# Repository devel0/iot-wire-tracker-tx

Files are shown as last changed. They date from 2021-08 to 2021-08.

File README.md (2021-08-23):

# iot-wire-tracker-tx

<!-- TOC -->
* [Description](#description)
* [Usage](#usage)
* [Notes](#notes)
* [Prototype example](#prototype-example)
* [How this project was built](#how-this-project-was-built)
<!-- TOCEND -->

<hr/>

## Description

Crude replacement for a damaged wire tracker tx module.

Generates a square signal train ( 50% duty ) on pin 9 suitable for a wire tracker receiver with follow train sequence:
- 50ms @2500 hz
- 50ms @833 hz
- 50ms @625 hz

Signal will completely disabled if red/black wire shorts due to triggering on pin 2 ; it will restart when short removed.

[schematic](https://oshwlab.com/lorenzo.delana/iot-wire-tracker-tx)

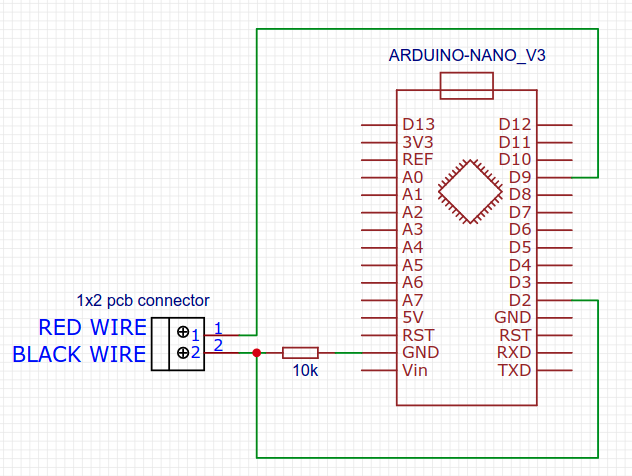
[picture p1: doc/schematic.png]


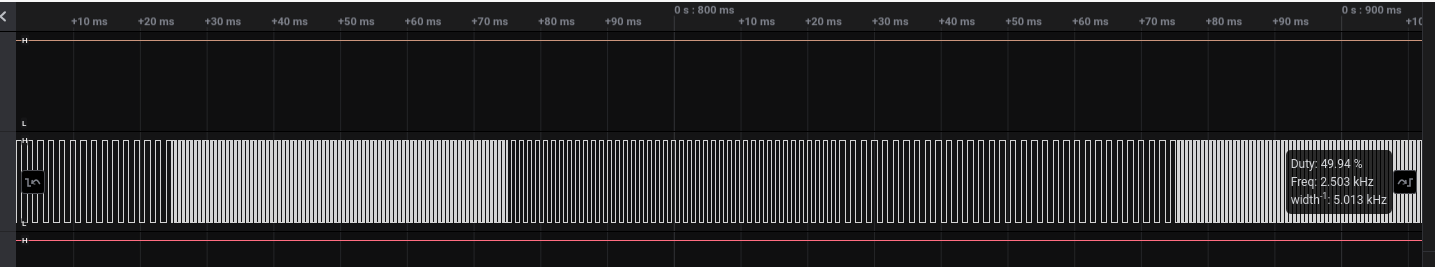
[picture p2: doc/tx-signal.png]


## Usage

example:
| **tx side** | **other side** |
|---|---|
| cable_txred | cable_unk1 |
| cable_black | cable_unk2 |
|  | ... |
|  | cable_unkX |

:warning: **Warnings** :
- ensure no voltage present on cables either for the tx side and other side cables

- connect cable_txred to the pin 9
- connect cable_black to the 10k resistor that in turn connects to GND 
- go to the other side with the wire tracker rx tool ( not provided ) that amplify into a speaker detected signal moving the point on wires
- two wires ( corresponding to the counterpart cable_txred and cable_black ) produces high volume on speaker
- counterverify if cable_unk1 e and cable_unk2 are those searched by connecting them together and if the speaker stop this mean that they are those matching source tx. during this phase the arduino led will blink fast.
- place a mark on two wires matched
- **important** : go to the tx side and disconnect cable_txred, cable_black before to reapply any voltage on cables or tx module could get damaged

## Notes
- 10k resistor allow to safely short circuit between red, black wire to cancel the signal in the counterverify step without destroy the pin9 port because of high level output while connects to gnd ( black cable )

## Prototype example

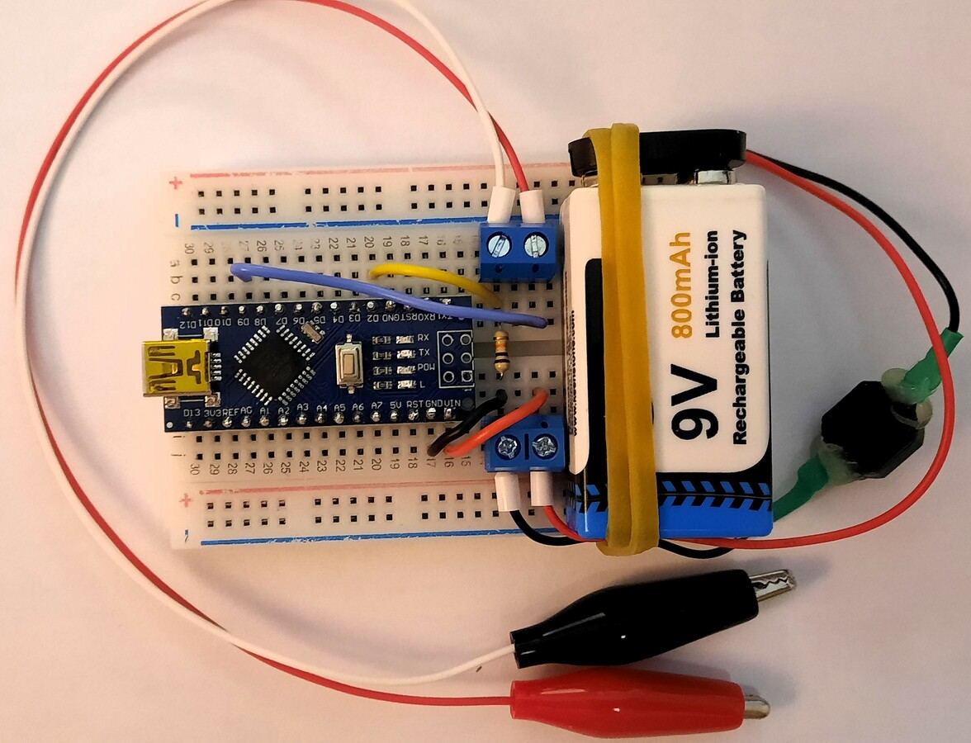
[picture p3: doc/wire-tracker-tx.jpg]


## How this project was built

- from platformio / projects / new selecting arduino nano (new bootloader)
- from platformio / libraries / added TimerInterrupt

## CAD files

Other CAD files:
arduino-nano.dwg

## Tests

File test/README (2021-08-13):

This directory is intended for PlatformIO Unit Testing and project tests.

Unit Testing is a software testing method by which individual units of
source code, sets of one or more MCU program modules together with associated
control data, usage procedures, and operating procedures, are tested to
determine whether they are fit for use. Unit testing finds problems early
in the development cycle.

More information about PlatformIO Unit Testing:
- https://docs.platformio.org/page/plus/unit-testing.html

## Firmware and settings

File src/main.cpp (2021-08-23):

// generates a square signal train ( 50% duty ) on pin 9
// suitable for a wire tracker transmitter
// RED WIRE -> pin 9
// BLACK WIRE -> 10k resistor -> gnd
//
// signal pattern sequence:
// - 50ms @2500 hz
// - 50ms @833 hz
// - 50ms @625 hz

// #define DEBUG // TODO: comment this on release

#include <Arduino.h>

#define OUT_PIN 9
#define IN_PIN 2
#define USE_TIMER_1 true

#include <TimerInterrupt.h>

#define TIMER_FREQ 10000

// 1/TIMER_FREQ * 2 * CNT_PHASE = 50ms phase switch time
int CNT_PHASE = 250;

bool val = false;
int val_cnt = 0;

int phase = 0;
int phase_cnt = 0;

volatile bool disabled = false;
volatile uint32_t m_in = millis();

void TimerISR()
{
  if (disabled)// && millis() - m_in > 500)
  {
    digitalWrite(OUT_PIN, HIGH);
    auto v = digitalRead(IN_PIN);
    if (v == LOW)
    {
      #ifdef DEBUG
      Serial.print(millis());
      Serial.println(" RE-ENABLE");
      #endif
      digitalWrite(LED_BUILTIN, LOW);
      disabled = false;
    }
    else
    {    
      return;
    }
  }

  if (phase_cnt > CNT_PHASE)
  {
    ++phase;
    if (phase > 2)
      phase = 0;
    phase_cnt = 0;
  }

  switch (phase)
  {

    // TIMER_FREQ / 4 = 2500hz
  case 0:
  {
    val = !val;
    digitalWrite(OUT_PIN, val ? HIGH : LOW);
  }
  break;

    // TIMER_FREQ / (4*3) = 833hz
  case 1:
  {
    if (val_cnt > 2)
    {
      val = !val;
      digitalWrite(OUT_PIN, val ? HIGH : LOW);
      val_cnt = 0;
    }
  }
  break;

    // TIMER_FREQ / (4*4) = 625hz
  case 2:
  {
    if (val_cnt > 3)
    {
      val = !val;
      digitalWrite(OUT_PIN, val ? HIGH : LOW);
      val_cnt = 0;
    }
  }
  break;
  }

  ++val_cnt;
  ++phase_cnt;
}

void inChgISR()
{
  //if (millis() - m_in > 500)
  if (!disabled)
  {
#ifdef DEBUG
    Serial.print(millis());
    Serial.println(" DISABLED");
#endif
    disabled = true;

    m_in = millis();
  }
}

void setup()
{
#ifdef DEBUG
  Serial.begin(38400);
  Serial.println("STARTUP");
#endif

  pinMode(IN_PIN, INPUT);
  pinMode(OUT_PIN, OUTPUT);
  pinMode(LED_BUILTIN, OUTPUT);
  digitalWrite(LED_BUILTIN, LOW);

  ITimer1.init();

  ITimer1.attachInterrupt(TIMER_FREQ, TimerISR, 0);

  attachInterrupt(digitalPinToInterrupt(IN_PIN), inChgISR, RISING);
}

uint32_t m_disabledLedBlink = 0UL;

void loop()
{
  if (disabled)
  {
    if (millis() - m_disabledLedBlink > 100)
    {
      digitalWrite(LED_BUILTIN, digitalRead(LED_BUILTIN) == LOW ? HIGH : LOW);
      m_disabledLedBlink = millis();
    }
  }
}

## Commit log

2021-08-23 added D2 input to stop signal emitting ; also blink led when signal stopped
2021-08-23 update pins map drawing
    [arduino-nano.dwg]
